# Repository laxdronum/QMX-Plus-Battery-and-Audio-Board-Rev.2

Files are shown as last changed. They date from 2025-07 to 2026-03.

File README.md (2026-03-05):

# QMX+ Battery & Audio Board/Shield - Rev. 2

This is the second revision of the custom battery and audio board designed for the QRP-Labs QMX+ transceiver. The module is designed to be directly mounted on the mainboard of the QMX+ and is now **compatible with both 9V and 12V QMX+ versions.**

### Review by Colin MM0OPX (Video): [This SIMPLE Mod Makes the QMX+ Even Better](https://www.youtube.com/watch?v=ZL12OHniudg)

---

## Features

- Integrated battery power supply
- Compatible with both 9V and 12V QMX+ transceivers
- MP2315 adjustable DC-DC converter onboard
- Built-in audio amplifier
- Direct mounting on QMX+ PCB
- Type-C port for charging
- Integrated BMS
- Easy to assemble and efficient design

## Revision History - Latest Revision: Rev. 2.0

- July 2025 Rev. 2.0 : Added support for 9V QMX+ by integrating an MP2315 buck converter to step down battery voltage. Minor layout and silkscreen adjustments made.

- March 2026 Rev. 2.1 : The text 'Made by' has been updated to 'Designed by' to comply with JLCPCB's policies.

## Images

Assembled Front
Assembled Back
Assembled Side
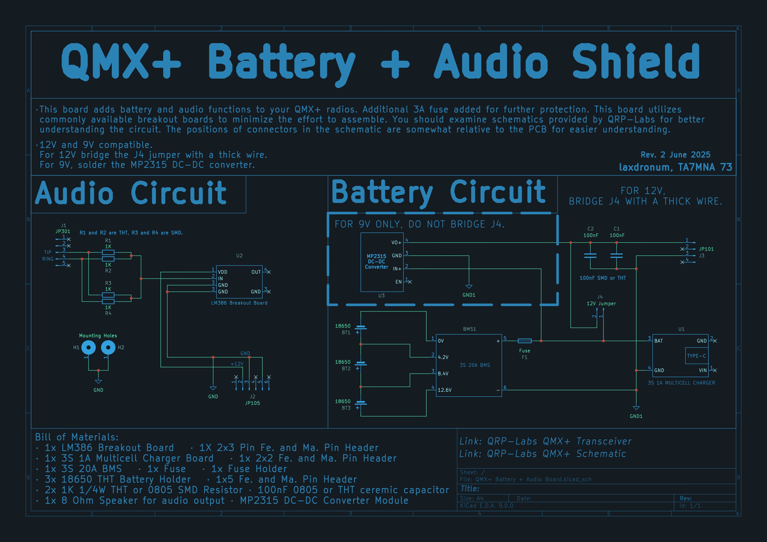
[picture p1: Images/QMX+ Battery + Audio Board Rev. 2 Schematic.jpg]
Schematic

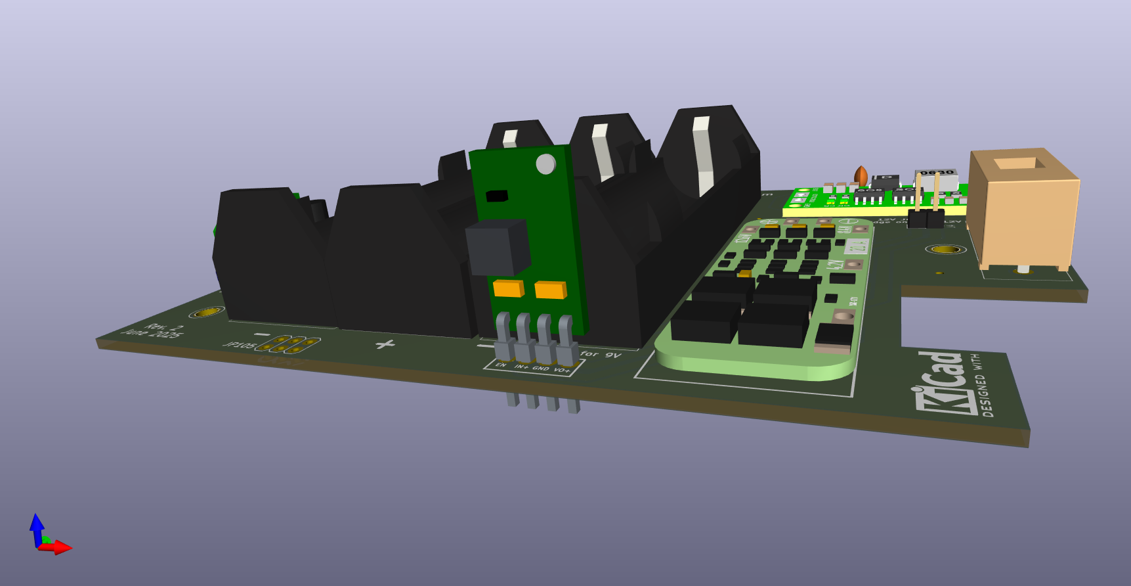
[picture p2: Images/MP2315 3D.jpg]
MP2315 3D View

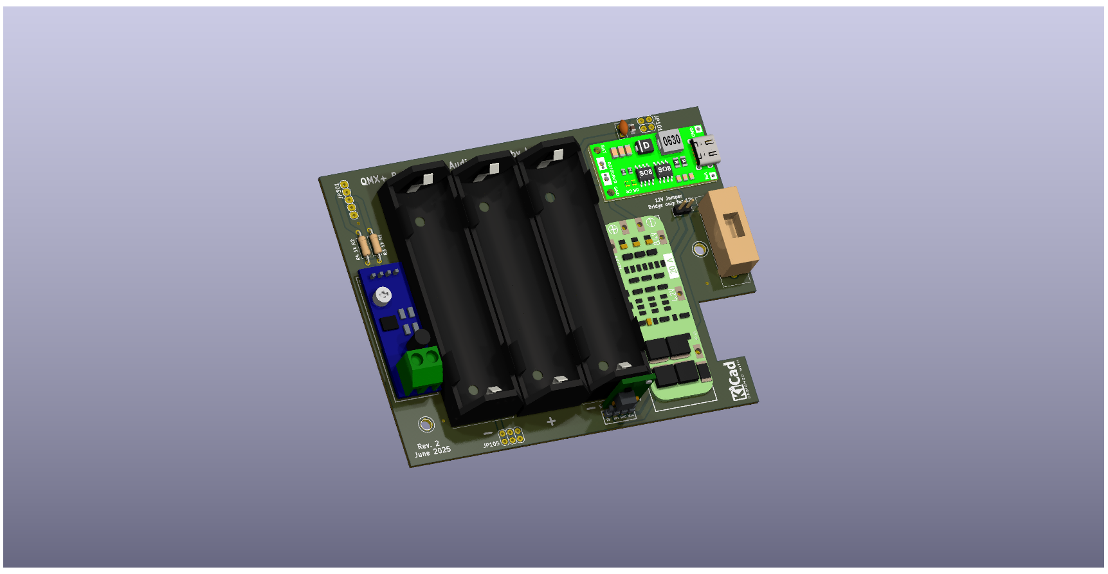
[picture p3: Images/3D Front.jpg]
3D Front

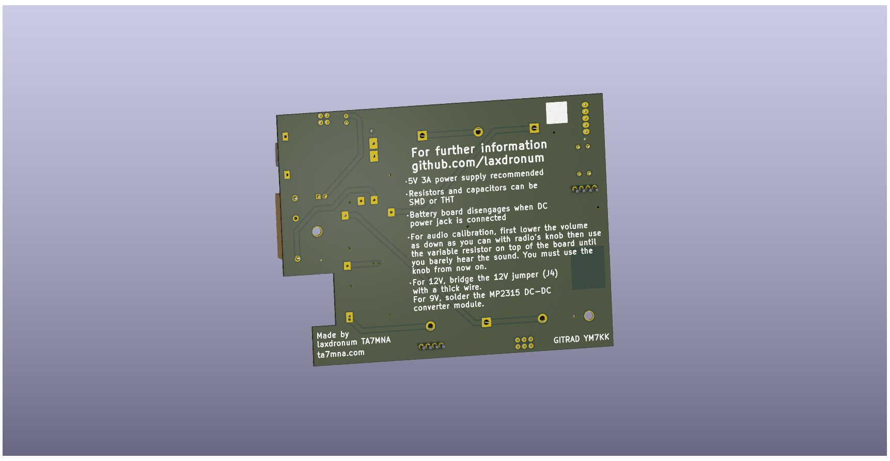
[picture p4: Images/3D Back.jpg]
3D Back


## Warning and Disclaimer

**Always power off your QMX+ before connecting and disconnecting DC power. Connecting and disconnecting DC power while the board is installed can cause voltage transients and may damage the mainboard.**

**This version is compatible with both 9V and 12V QMX+ units. You must adjust the MP2315 output voltage correctly to 9V before first use. You must not solder the DC-DC converter if you want to use the board 12V.**

**Use at your own risk. Incorrect wiring or voltage configuration can damage your radio. I am not responsible for any damage, injury, or consequences resulting from use or misuse of this board.**

**Please do not copy or rebrand this project. You are free to use it with my labels.**

## Required Components

- **3x 1x18650 Li-ion Batteries:** I used 2900mAh INR18650 cells. There must be three 1x18650 battery holders.
- **3S 1A Multi Cell Charger Board (DDTCCRUB):** I used 1A and 2A versions. 3A might be a problem due to heating.
- **1x 3S 20A BMS Board**
- **1x LM386 Audio Amplifier Breakout Board:** You have to desolder the pins.
- **1x 5x20mm 3A Fuse:** For further protection.
- **1x 5x20mm Fuse Holder:** Compatible with most 2 pin 5x20mm fuse holders. It must have 22.86mm (0.9in) or 15.24mm (0.6in) pin pitch.
- **2x 1K 1/4W THT or 0805 SMD Resistors:** Solder as you like SMD or THT.
- **8 Ohm Speaker:** Necessary for audio output. Use the screw terminals on the audio amplifier board. Small laptop speakers should work.
- **1x 2x3, 1x 2x2, 1x 1x5 2.54mm Female and Male Pin Headers:** To mount the PCB directly on the main board.

#### For 9V:

- **MP2315 DC-DC Buck Converter**
- **1x4 90 Degree Male Header**

## Assembly and Calibration

### Assembly

Check the ASSEMBLY.md file. Everything is same as Rev. 1.x if you are building it for 12V.

### Audio Calibration

After assembly and testing that your radio works you must calibrate the audio.

To calibrate the audio you must first lower the volume as down as you can using the volume knob of the radio. Then you must turn the variable resistor found on the audio board until you can hear the audio coming from the speaker barely. Audio is calibrated, you should use the volume knob from now on.

## Notes on RFI

Since there is an RFI source inside the enclosure, some noise may occur in the 9V models. However, the 12V versions are free from battery board-induced noise, except during charging. Please keep this in mind when using it with 9V models.

> **In our tests with the 9V regulator, we observed that it caused QRM at certain frequencies. However, this noise was often at a lower level than QMX’s own birdies and was not disturbing. When we connected an antenna to the QMX and listened, the noise remained below the noise level coming from the antenna.**

## Notes

- Some power adapters are not working with this battery charger module (DDTCCRUB) because it lacks power delivery (PD) technology. If your charger doesn't work try another charger.
- If you power the radio with DC jack while battery pack is installed, QMX+ will disconnect the batteries from radio. You can only charge the batteries from the Type-C port. QMX+'s own Type-C port is only for data.
- The 8mm x 8mm square behind the board is for JLCPCB order number. Select the **'2D Barcode' option and specify position** while ordering.

## Links

- [QRP-Labs Website](https://www.qrp-labs.com)
- [QRP-Labs QMX+ Transceiver](https://qrp-labs.com/qmxp.html)

### Special thanks to Hans Summers (G0UPL) for making this project possible.

### TA7MNA – laxdronum – GITRAD Radio Club YM7KK

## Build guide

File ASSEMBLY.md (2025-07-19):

# **Assembly Guide**

---

## **Step 1 – Parts Needed**

Step 1 Photo

---

## **Step 2 – Solder the Battery Holders**

Solder the battery holders to the board and pay close attention to the polarity.

Step 2 Photo

---

## **Step 3 – Solder the BMS**

Modules should be soldered on top of 2.54mm standard pin headers. Insert the headers into the appropriate holes for different versions of the BMS module.

### **Step 3.1 – Insert the Pin Headers One by One**

Step 3.1 Photo

### **Step 3.2 – Solder the BMS and the Header Pins to the Board**

Clamping the module onto the board, as shown in the photo below, really helps.

Step 3.2 Photo

---

## **Step 4 – Solder the Charging Module and the Fuse Holder**

Solder the charging module in the same way as the BMS. You should align the Type-C port with the edge of the PCB if it is misaligned.

Step 4 Photo

### **Step 4.1 – Solder the Fuse Holder**

The fuse holder must have either 600mil (15.24mm) or 900mil (22.86mm) pin spacing.

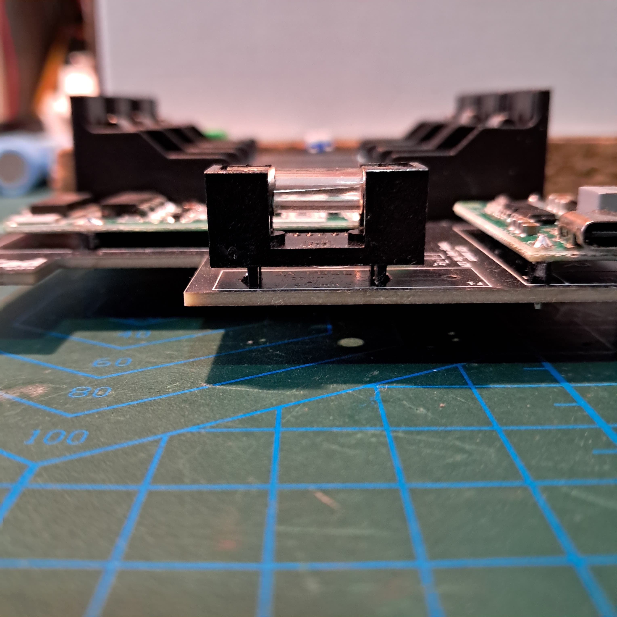
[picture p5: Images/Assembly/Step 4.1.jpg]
Step 4.1 Photo


---

## **Step 5 – Solder the Audio Amplifier Module and the Resistors**

### **Step 5.1 – Reversing the Pins**

Soldering the audio module requires some skill. It comes with 1x4 headers pre-soldered, but you have to desolder them and solder another 1x4 header on the opposite side.

Step 5.1 Photo

### **Step 5.2 – Soldering onto the Board**

Placing some type of foam or double-sided tape under the board helps prevent excessive bending of the audio amp PCB.

Step 5.2 Photo

### **Step 5.3 – Soldering the Resistors**

You can solder either 0805 SMD or 1/4W THT resistors. I chose THT for this board.

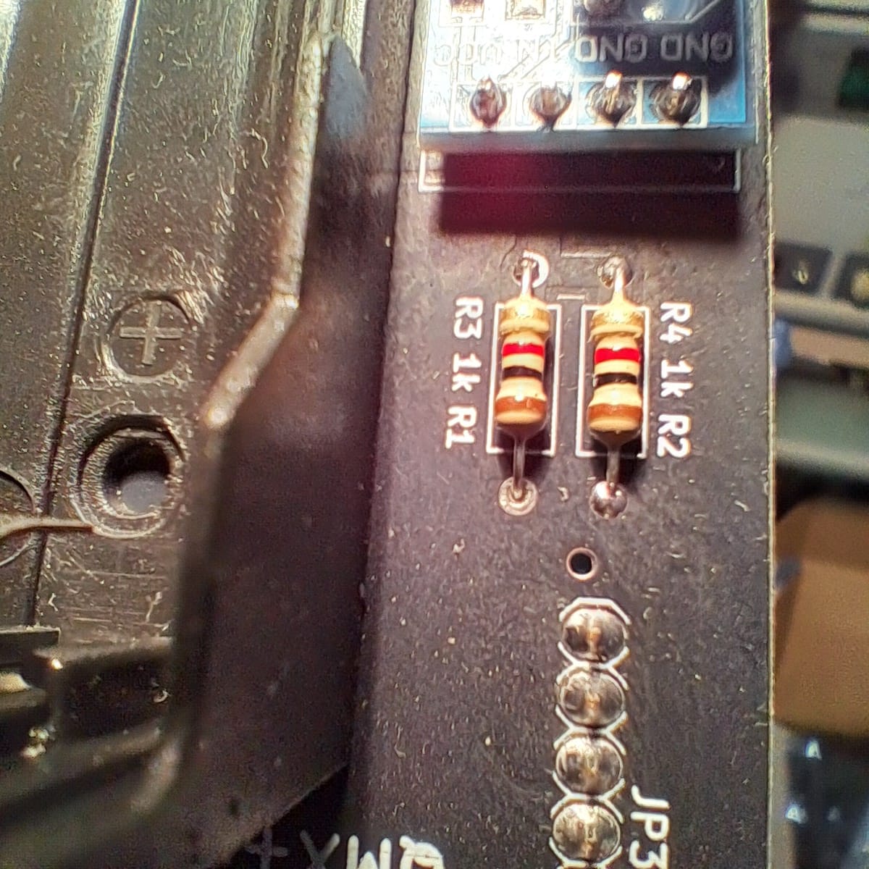
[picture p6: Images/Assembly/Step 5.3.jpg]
Step 5.3 Photo


---

## **Step 6 (For 12V Boards) – Bridging the J4 Pad**

Short the J4 pad with a thick wire.

---

## **Step 6 (For 9V Boards) – Preparing and Soldering the Buck Converter**

> **Do not solder the buck converter and bridge the J4 at the same time. Magic smoke will appear.**

### **Step 6.1 – Inspecting the DC-DC Converter**

If you look closely, you'll see a few pads behind it. The ADJ pad is shorted by default. You need to cut the pad in the middle to disable its adjustment mode.

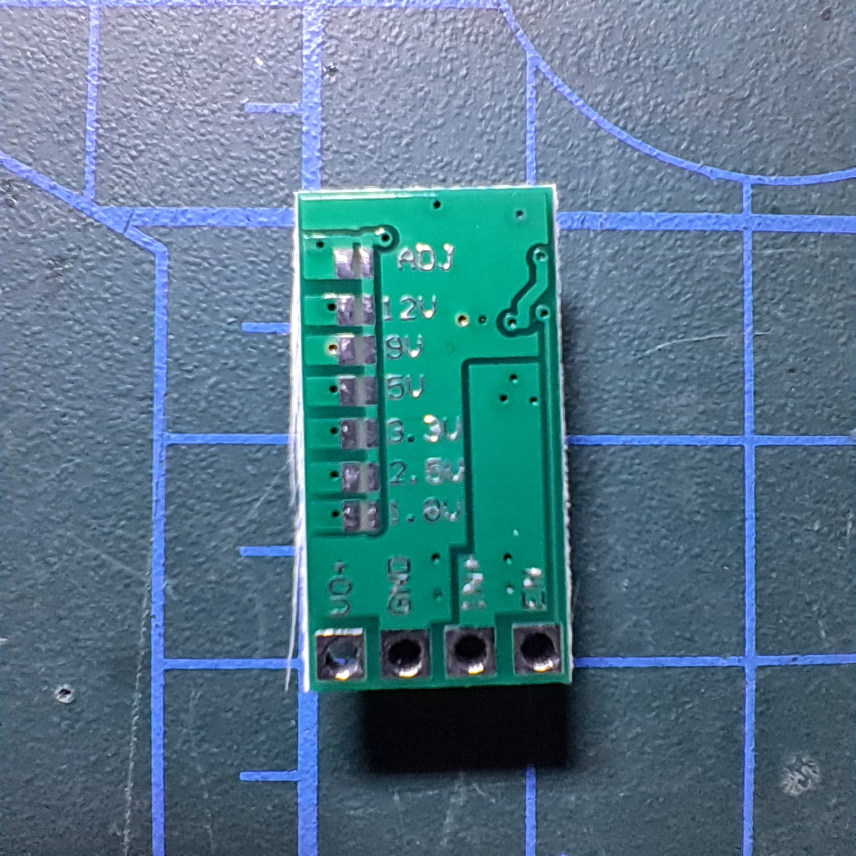
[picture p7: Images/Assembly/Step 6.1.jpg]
Step 6.1 Photo


### **Step 6.2 – Cutting the ADJ Pad and Soldering the 9V Pad**

You can cut the pad with an X-Acto knife. You need to go a little bit deep to sever the copper trace. Test it with a multimeter after cutting. After cutting, you must short the 9V pad with solder behind the converter.

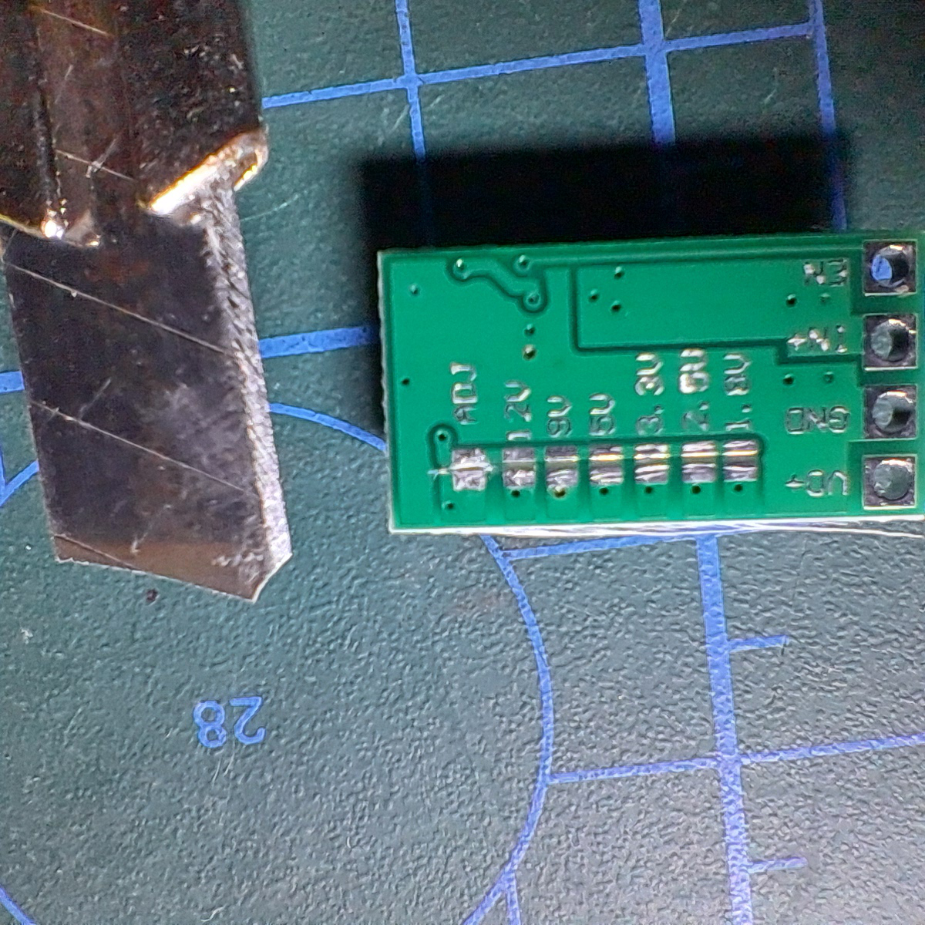
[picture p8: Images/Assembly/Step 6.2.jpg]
Step 6.2 Photo


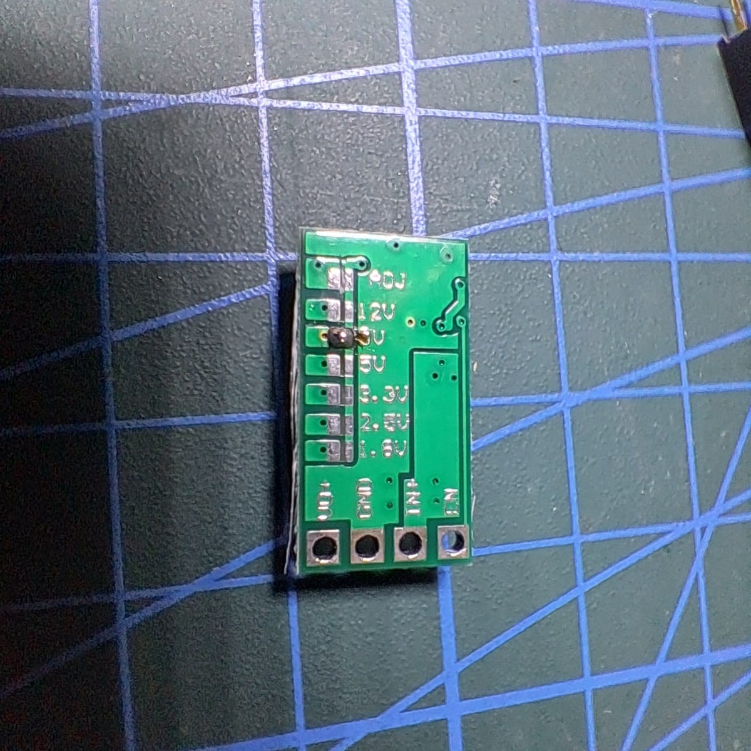
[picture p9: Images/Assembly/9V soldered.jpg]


### **Step 6.3 – Soldering the Headers**

You must solder the header pins in reverse. The longer pins must protrude from the back. If you solder the headers in the usual way, the buck converter won’t fit into place.

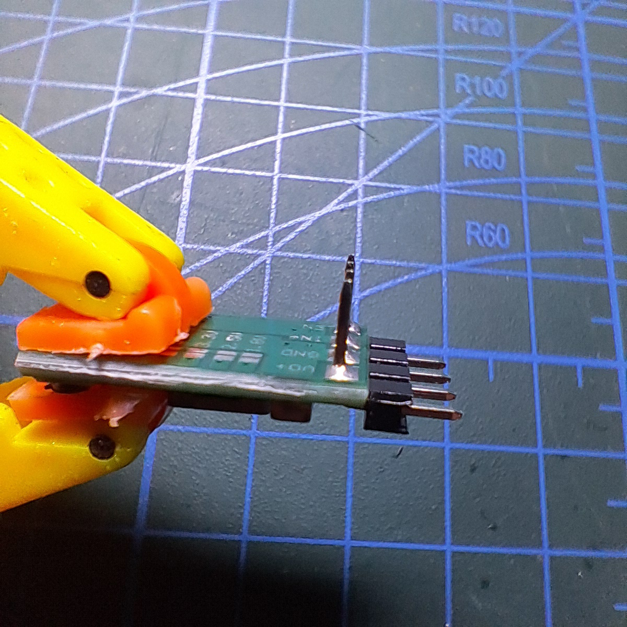
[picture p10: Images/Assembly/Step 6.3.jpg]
Step 6.3 Photo


### **Step 6.4 – Soldering the Module onto the Board**

This is the easiest step. Trim the protruding headers of the converter module and solder it in place. There is a place for either 100nF THT or 0805 SMD ceramic capacitor near the JP101. The capacitor is optional.
**Never solder the DC-DC converter and short the J4 pads at the same time.**

Step 6.4 Photo

---

## **Step 7 – Shorten the Pins**

Now that all modules are soldered onto the board, you must shorten the pins on the backside of the board.

Step 7 Photo

---

## **Step 8 – Solder the Headers to the Board**

Soldering female headers to the battery board is recommended. This helps prevent shorts during handling.

Step 8 Photo

---

## **Step 9 – Solder the Corresponding Male Headers onto the QMX+**

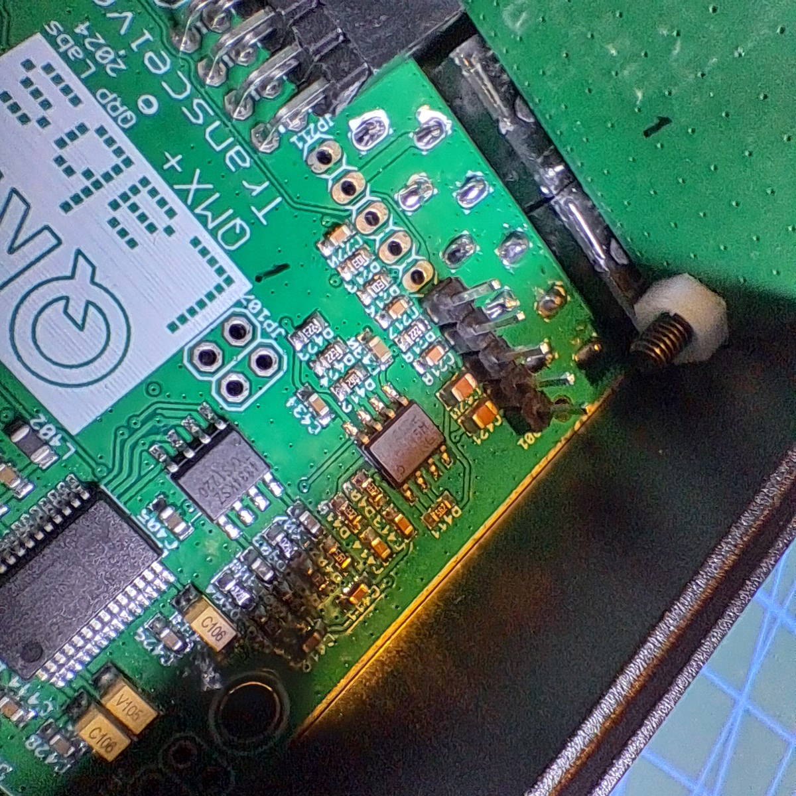
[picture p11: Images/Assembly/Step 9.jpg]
Step 9 Photo


---

## **Step 10 - Assembly Finished**

Assembly is finished. You must test the board with a multimeter according to the schematic.

Finished 1 Photo

Finished 2 Photo

---

## Audio Calibration

- Set radio volume to minimum.
- Adjust the LM386 board's variable resistor until audio is barely audible.
- Use radio's volume knob for future control.

--- 

## Drilling a Hole in the Backplate

This step can be a bit tricky. First, you need to mount the board on top of the mainboard and secure it using 11 mm nylon hex spacers. Then, mark the backplate accordingly for drilling. Screwing the board in place ensures proper alignment and helps prevent mistakes.

On the first radio where I installed my board, I made the mistake of not aligning it properly — the charging port ended up slightly higher than the hole. Fortunately, it still works.

---

## Adding a Speaker

For the speaker, you can use a 0.5W or 1W 8-ohm speaker. Small laptop speakers matching those values should work as well. I attached the speaker on top of the BMS using double-sided foam tape. When the enclosure is screwed down, the top cover presses against the speaker, holding it securely in place.

---

## Notes on RFI

Since there is an RFI source inside the enclosure, some noise may occur in the 9V models. However, the 12V versions are free from battery board-induced noise, except during charging. Please keep this in mind when using it with 9V models.

> **In our tests with the 9V regulator, we observed that it caused QRM at certain frequencies. However, this noise was often at a lower level than QMX’s own birdies and was not disturbing. When we connected an antenna to the QMX and listened, the noise remained below the noise level coming from the antenna.**

**If you have any questions, feel free to send me an email**
**mnecatianky@gmail.com**

**Necati 73.**
**ta7mna.com**

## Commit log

2025-07-19 Uploaded Gerbers
    [QMX+ Battery + Audio Board-B_Cu.gbr, QMX+ Battery + Audio Board-B_Mask.gbr, QMX+ Battery + Audio Board-B_Paste.gbr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]
2026-03-05 Rev 2.1 - minor silkscreen change
    [QMX+ Battery + Audio Board-B_Cu.gbr, QMX+ Battery + Audio Board-B_Mask.gbr, QMX+ Battery + Audio Board-B_Paste.gbr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]
